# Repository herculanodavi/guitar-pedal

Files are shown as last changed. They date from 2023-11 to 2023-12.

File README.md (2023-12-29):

# guitar-pedal
Electronics project for the course Mixed-Signal Hardware Design with KiCad by Philip Salmony

## System Design
[System Requirements](system_design/requirements.md)

[Part Number Selection](system_design/part_selection.md)

## PCB
[Kicad Schematics](pcb/kicad)

[LTSpice Simulation Files](pcb/simulation)

[Gerber Files](pcb/gerber)

## Firmware
[Firmware Project](firmware)

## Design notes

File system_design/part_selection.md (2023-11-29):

# Part Selection

Given the reference design of the course, parts will only be different if there is a special reason to it, as part out of stock or additional functionality.

## Effect controls

- **Bistable buttons with LED:** LP4EE1PBCTR. It's a relatively cheap latched button with illumination. 2.2V illumination voltage and 0.1A current rating for 200mcd, so its consumption will be 1.5mA. 
- **Knobs for filter parameters:** PTV09A-4020F-B103. A cheap 10k linear single-gang potentiometer from Bourns.
- **Bistable footswitch:** (searching)
- **LED indicator:** T1341MND-20P000312U1930. The cheapest 1206 white LED I could find.
  
## USB

- **Receptacle:** 10164359-00011LF, the cheapest USB-C connector available in Digikey that is in stock.
- **ESD protection:** USBLC6-2SC6, from reference design.

## Processor

The suggested processor, STM32F103CBT6TR, is more expensive than STM32F401RBT6, while the F4 model has a Arm Core M4
and more RAM. The increased number of pins (from LQFP48 to LQFP64) is not an issue since this design is not constrained by space.

The main difference between our application and the one from the reference design is that we want to support a continuous and low-latency calculation of effects, and these are not yet specified. Thus, the trade-off of performance for space is advantageous. 

**Chosen part:** STM32F401RBT6

## Power supplies

Since requirements have no differences from the reference design, the parts will be the same. Reason to look for another pair of converters could if we had wanted to allow for the negotiable 500mA power consumption and consume more current (even so, this part would also be sufficient). At the time of the project, HT7533-1 was out of stock, so we chose a similar part: LDLN025M33R.

**Chosen parts:** TLV62569PDRLR (Buck) and LDLN025M33R (LDO).

## Converters

Since requirements have no differences from the reference design, the parts should be the same. Reason to look for another pair of converters could be to have a single-ended ADC or to invest in higher-performance parts, but these are not yet important enough to look for different parts. At the time of the project, both parts are active and in stock in Digikey.

**Chosen parts:** ADC141S616CIMM/NOPB (14-bit, 50-250kSPS, differential) and DAC7563SDGSR (12-bit, single-ended).

## Analogue sections

OPAmp part is the same as the reference design.

**Chosen part:** MCP6001

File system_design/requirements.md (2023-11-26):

# Guitar Pedal basic requirements

This is the project of a digital guitar pedal. It's a USB-powered, single-channel, low-frequency signal analyser and generator.

* USB-powered: less than 500mA current consumption, 5V input voltage, USB communication for configuring filter parameters.
* Low-frequency: Audio band (20Hz to 20kHz).
* Signal analyzer: captures the guitar signal input with an ADC for the digital generation of effects.
* Signal generator: transforms the generated guitar sound with effect back into analog.

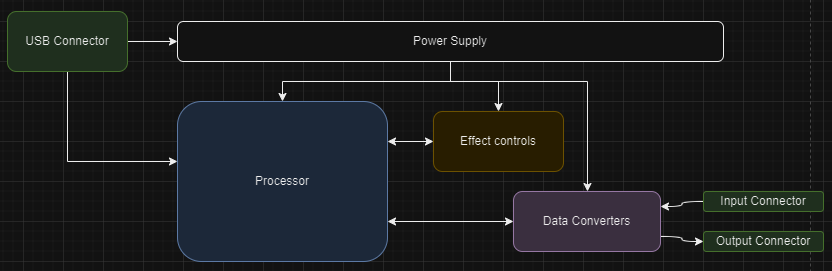
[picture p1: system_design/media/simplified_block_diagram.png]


# System requirements

Given basic requirments, let's dive deeper into each subsystem.

### Effect controls

- Two effects controls:
  - One latched pushbutton with LED for activation with 15mcd illuminance.
  - Three knobs for effect parameters.
- One footswitch for effect set.
- One LED with 15mcd illuminance for active mode indication.
- All controls should have ESD protection.

### USB

- **Bit rate:** audio band has max frequency of 20kHz, so sampling rate is at least 40kHz. Given a digital audio signal of 16 bits and a sampling rate of 2 times the minimum (80kHz), the minimum data rate is 1.28Mbits/s.
- **USB Version:** USB 2.0 FS is used: 12Mbits/s.
- **USB Connector:** USB Type C.
- **USB Power-only:** System should also work (pedal effects) with USB without data lines.

### Processor

- **Peripherals:**
  - USB for data streaming.
  - 2x SPI: ADC and DAC.
  - 6x ADC channel for effect knobs.
  - 3x GPIO input for activation buttons.
  - 1-3x GPIO output for LED (depending on the particular button with LED).
- **Core, packaging and brand:**
  - **Core:** Not much power needed, ARM Cortex M0 or M1 is enough.
  - **Package:** Avoid BGA and QFN
  - **Brand:** STM32

### Power supples
- Split digital and analogue supplies
  - Digital: switching supply for efficiency.
  - Analogue: LDO for noise performance.
- Input power from USB:
  - Noisy power rail.
  - Input voltage from 4.5V to 5V.
  - 500mA maximum current if negotiated, 150mA otherwise, so system should consume less than 150mA.

### Converters
- **Interface:** SPI
- **Bit depth:** 14-bit for ADC, 12-bit for DAC
- **Conversion:** Preferrably single-ended
- **Sampling rate:** At least 48kHz

### Analogue sections
- Input:
  - Greater than 1MOhm input buffer, ESD protection, RF filtering.
  - Anti-aliasing filter with cut-off at max half the ADC sampling rate.
- Output:
  - Smaller than 50Ohm outpuf buffer, ESD protection.
  - Anti-aliasing filter with cut-off at max half the DAC sampling rate.

### Miscellaneous
- **Additional connectors:** Tag-connect for firmware development.
- **Audio connectors:** TS 1/4”

## Requirements Draft

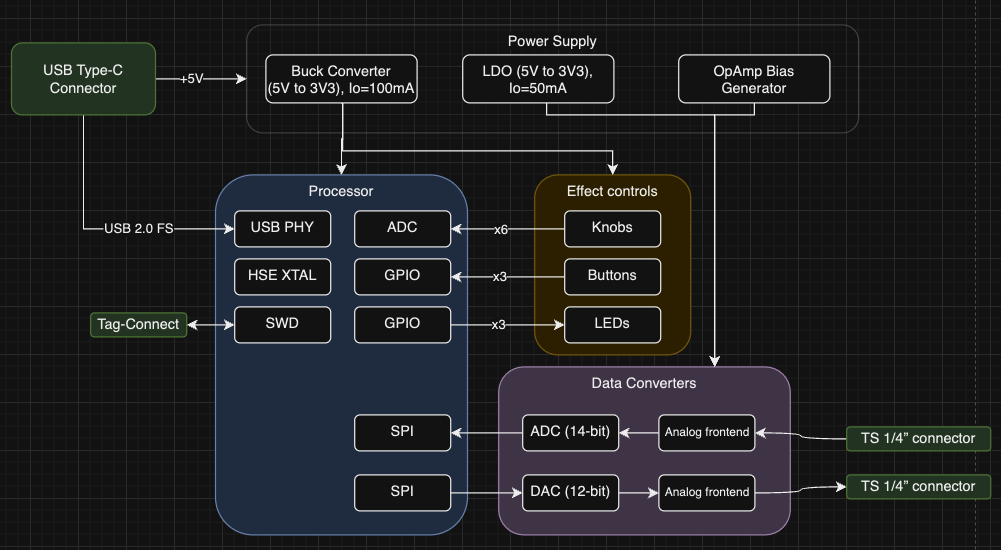
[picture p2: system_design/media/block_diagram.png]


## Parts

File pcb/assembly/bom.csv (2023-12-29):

Reference | Value | Footprint | Datasheet | Part Number | Part number | Supplier Link | Qtd
C201, C202, C306, C609 | 1u | Capacitor_SMD:C_0805_2012Metric | ~ | CC0805KKX7R7BB105 |  |  | 4
C203-C206, C208, C501 | 22u | Capacitor_SMD:C_0805_2012Metric | ~ | C0805C226M8PAC7210 |  |  | 6
C207 | DNP | Capacitor_SMD:C_0805_2012Metric | ~ |  |  |  | 1
C209, C302, C303, C305, C307, C309, C310, C312, C401-C409, C604, C607, C608, C611, C612, C614, C619, C622 | 100n | Capacitor_SMD:C_0805_2012Metric | ~ | CC0805JRX7R9BB104 |  |  | 25
C301, C311 | 4.7u | Capacitor_SMD:C_0805_2012Metric | ~ | C0805C475M4RACTU |  |  | 2
C304, C308 | 10p | Capacitor_SMD:C_0805_2012Metric | ~ | C0805C100M4GACTU |  |  | 2
C601-C603, C605, C610, C615 | 10u | Capacitor_SMD:C_0805_2012Metric | ~ | C0805C106M8RACTU |  |  | 6
C606, C618, C621, C623 | 150p | Capacitor_SMD:C_0805_2012Metric | ~ | 885012207111 |  |  | 4
C613, C616, C617, C620 | 1n | Capacitor_SMD:C_0805_2012Metric | ~ | C0805C102K2RAC |  |  | 4
D301-D305, D401-D405, D601, D602 | ~ | pedal-components:PESD3V3L1BA | PESD3V3L1BA | PESD3V3L1BA,115 |  |  | 12
H101-H105 | MountingHole | MountingHole:MountingHole_3.2mm_M3_DIN965_Pad | ~ |  |  |  | 5
J301 | TagConnect_TC2030 | Connector:Tag-Connect_TC2030-IDC-FP_2x03_P1.27mm_Vertical | https://www.tag-connect.com/wp-content/uploads/bsk-pdf-manager/TC2030-CTX_1.pdf |  |  |  | 1
J501 | USB4105-GF-A | Connector_USB:USB_C_Receptacle_GCT_USB4105-xx-A_16P_TopMnt_Horizontal | https://www.usb.org/sites/default/files/documents/usb_type-c.zip | USB4105-GF-A |  | https://www.digikey.de/en/products/detail/gct/USB4105-GF-A/11198441 | 1
J601, J602 | NMJ4HCD2 | pedal-components:NMJ4HCD2 |  | NMJ4HCD2 |  | https://www.mouser.de/ProductDetail/Neutrik/NMJ4HCD2?qs=SzdD80gJ2cAr9Xh3wJi7nw%3D%3D | 2
L201 | 10n | Inductor_SMD:L_0805_2012Metric | ~ | 0805CS-100EGTS |  |  | 1
L202 | 68u | pedal-components:ASPI-4030S-680M-T |  | ASPI-4030S-680M-T |  | https://www.digikey.de/en/products/detail/abracon-llc/ASPI-4030S-680M-T/5055591 | 1
R201 | 10R | Resistor_SMD:R_0805_2012Metric | ~ | RNCP0805FTD10R0 |  |  | 1
R202 | 100k | Resistor_SMD:R_0805_2012Metric | ~ | RT0805FRE07100KL |  |  | 1
R203 | 22k | Resistor_SMD:R_0805_2012Metric | ~ | RT0805FRE1322KL |  |  | 1
R204, R205 | 1k | Resistor_SMD:R_0805_2012Metric | ~ | RT0805FRE071KL |  |  | 2
R301, R609 | 0R | Resistor_SMD:R_0805_2012Metric | ~ | CRCW08050000Z0EC |  |  | 2
R302-R305, R601, R613 | 49.9R | Resistor_SMD:R_0805_2012Metric | ~ | CMP0805AFX-49R9ELF |  |  | 6
R306, R605 | 10K | Resistor_SMD:R_0805_2012Metric | ~ | AC0805FR-0710K5L |  |  | 2
R401-R407, R602, R614, R615 | 1K | Resistor_SMD:R_0805_2012Metric | ~ | RT0805FRE071KL |  |  | 10
R501, R502 | 5K1 | Resistor_SMD:R_0805_2012Metric | ~ | RT0805FRE135K1L |  |  | 2
R603, R604 | 2M2 | Resistor_SMD:R_0805_2012Metric | ~ | RCV08052M20FKEA |  |  | 2
R606, R608 | 6K8 | Resistor_SMD:R_0805_2012Metric | ~ | RT0805BRD076K8L |  |  | 2
R607, R611 | 22K | Resistor_SMD:R_0805_2012Metric | ~ | RT0805FRE1322KL |  |  | 2
R610, R612 | 12K | Resistor_SMD:R_0805_2012Metric | ~ | RP0805FRE0712KL |  |  | 2
RV401-RV406 | 50K Linear | pedal-components:PTV09A-4030S-A503 | ~ | PTV09A-4030S-A503 |  | https://www.digikey.de/en/products/detail/bourns-inc/PTV09A-4030S-A503/7314966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 | 6
SW401 | PBS-24-202P | pedal-components:FSW-DPDT-020 | ~ |  |  |  | 1
SW402, SW403 | LP4EE1PBCTR | pedal-components:LP4EE1PBCTR |  | LP4EE1PBCTR |  | https://www.digikey.de/en/products/detail/e-switch/LP4EE1PBCTR/4028429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 | 2
U201 | HT7533-1 | Package_TO_SOT_SMD:SOT-89-3 | https://www.holtek.com/documents/10179/116711/HT75xx-1v250.pdf |  |  |  | 1
U202 | TLV62569DBV | Package_TO_SOT_SMD:SOT-23-5 | http://www.ti.com/lit/ds/symlink/tlv62569.pdf | TLV62569DBVR |  | https://www.digikey.de/en/products/detail/texas-instruments/TLV62569DBVR/6580119 | 1
U203, U603, U605, U606 | MCP6001-OT | Package_TO_SOT_SMD:SOT-23-5 | http://ww1.microchip.com/downloads/en/DeviceDoc/21733j.pdf | MCP6001UT-I/OT |  | https://www.digikey.de/en/products/detail/microchip-technology/MCP6001UT-I-OT/562450 | 4
U301 | STM32F401RBTx | Package_QFP:LQFP-64_10x10mm_P0.5mm | https://www.st.com/resource/en/datasheet/stm32f401rb.pdf | STM32F401RBT6TR |  | https://www.digikey.de/en/products/detail/stmicroelectronics/STM32F401RBT6TR/5268280 | 1
U501 | USBLC6-2SC6 | Package_TO_SOT_SMD:SOT-23-6 | https://www.st.com/resource/en/datasheet/usblc6-2.pdf | USBLC6-2SC6 |  | https://www.digikey.de/en/products/detail/stmicroelectronics/USBLC6-2SC6/1040559 | 1
U601 | REF3033 | Package_TO_SOT_SMD:SOT-23 | http://www.ti.com/lit/ds/symlink/ref3033.pdf | REF3033AIDBZR |  | https://www.digikey.de/en/products/detail/texas-instruments/REF3033AIDBZR/1573916 | 1
U602 | DAC7563SDGSR | pedal-components:10-VSSOP-TI |  | DAC7563SDGSR |  | https://www.digikey.de/en/products/detail/texas-instruments/DAC7562SDGSR/2687106 | 1
U604 | ADC141S626 | pedal-components:10-VSSOP-TI |  | ADC141S626 |  | https://www.digikey.de/en/products/detail/texas-instruments/ADC141S626CIMM-NOPB/1835976 | 1
Y301 | 16MHz | pedal-components:RH100-16.000-8-2020-TR | ~ | RH100-16.000-8-2020-TR |  | https://www.digikey.com/en/products/detail/raltron-electronics/RH100-16-000-8-2020-TR/15963324 | 1

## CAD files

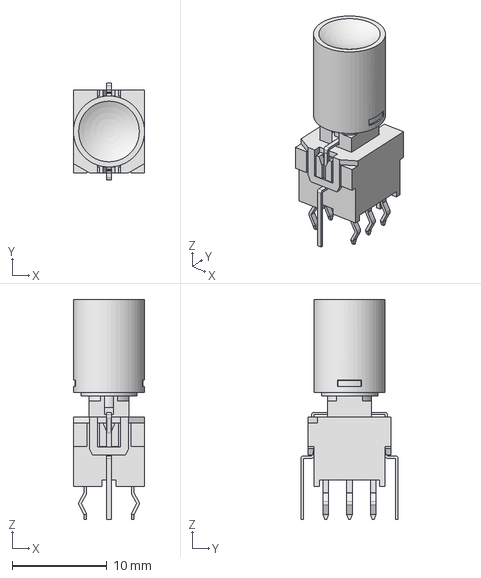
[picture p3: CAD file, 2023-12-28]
pcb/3d_model/components/LP4EE1PBCTR.stp
7.50 x 10.2 x 23.2 mm

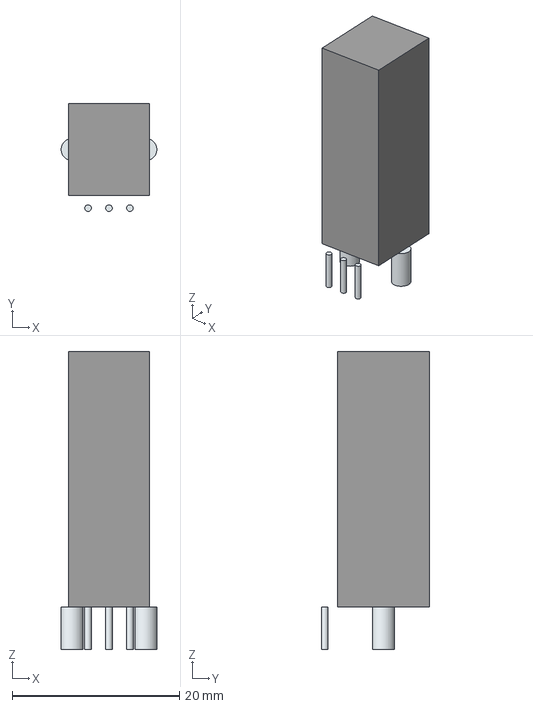
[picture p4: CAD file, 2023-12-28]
pcb/3d_model/components/PTV09A-4030S-A503.stp
11.4 x 12.9 x 35.6 mm
Leads

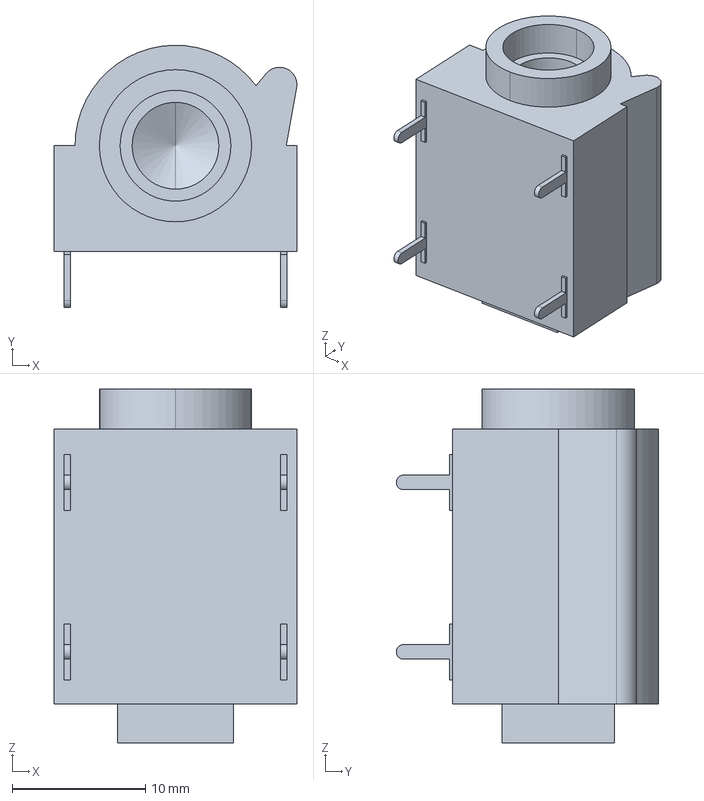
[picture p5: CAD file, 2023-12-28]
pcb/3d_model/components/d-nmj4hcd2.stp
18.2 x 19.7 x 26.5 mm

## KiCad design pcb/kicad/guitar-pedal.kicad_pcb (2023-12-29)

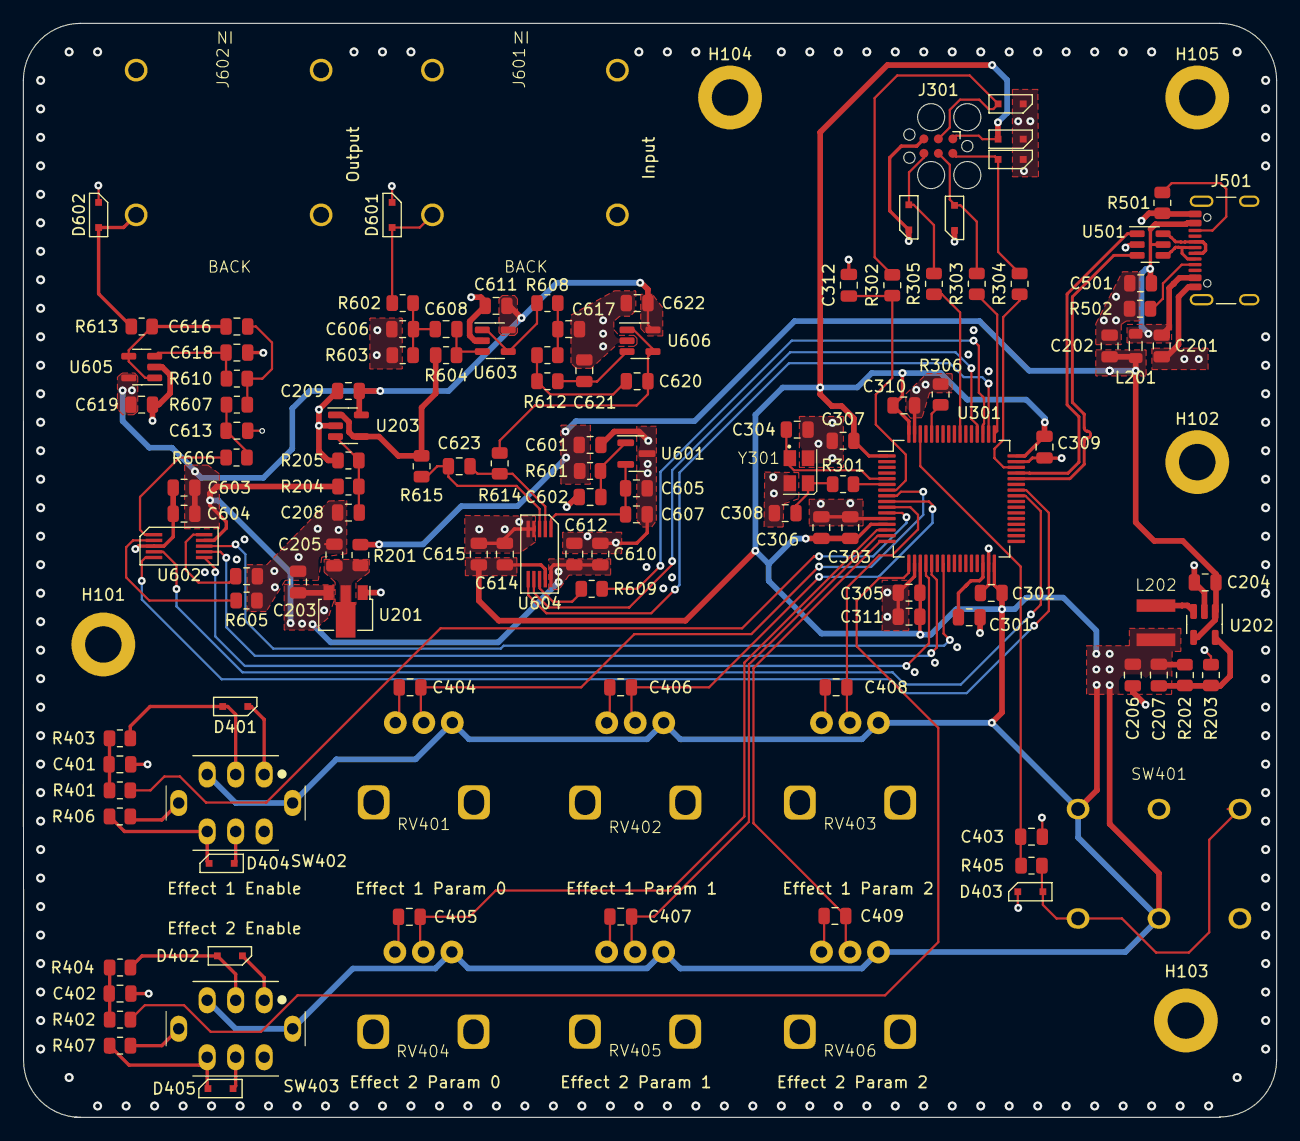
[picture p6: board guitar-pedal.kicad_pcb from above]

Board: 4 copper layers, 110.0 x 96.0 mm, 133 parts (0 on the bottom side), 76 nets.

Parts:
C201, C202, C306, C609: 1u; C_0805_2012Metric
C203, C204, C205, C206, C208, C501: 22u; C_0805_2012Metric
C207: DNP; C_0805_2012Metric
C209, C302, C303, C305, C307, C309, C310, C312, C401, C402, C403, C404, C405, C406, C407, C408, C409, C604, C607, C608, C611, C612, C614, C619, C622: 100n; C_0805_2012Metric
C301, C311: 4.7u; C_0805_2012Metric
C304, C308: 10p; C_0805_2012Metric
C601, C602, C603, C605, C610, C615: 10u; C_0805_2012Metric
C606, C618, C621, C623: 150p; C_0805_2012Metric
C613, C616, C617, C620: 1n; C_0805_2012Metric
D301, D302, D303, D304, D305, D401, D402, D403, D404, D405, D601, D602: PESD3V3L1BA
H101, H102, H103, H104, H105: MountingHole; MountingHole_3.2mm_M3_DIN965_Pad
J301: TagConnect_TC2030; Tag-Connect_TC2030-IDC-FP_2x03_P1.27mm_Vertical
J501: USB4105-GF-A; USB_C_Receptacle_GCT_USB4105-xx-A_16P_TopMnt_Horizontal
J601, J602: NMJ4HCD2
L201: 10n; L_0805_2012Metric
L202: 68u; ASPI-4030S-680M-T
R201: 10R; R_0805_2012Metric
R202: 100k; R_0805_2012Metric
R203: 22k; R_0805_2012Metric
R204, R205: 1k; R_0805_2012Metric
R301, R609: 0R; R_0805_2012Metric
R302, R303, R304, R305, R601, R613: 49.9R; R_0805_2012Metric
R306, R605: 10K; R_0805_2012Metric
R401, R402, R403, R404, R405, R406, R407, R602, R614, R615: 1K; R_0805_2012Metric
R501, R502: 5K1; R_0805_2012Metric
R603, R604: 2M2; R_0805_2012Metric
R606, R608: 6K8; R_0805_2012Metric
R607, R611: 22K; R_0805_2012Metric
R610, R612: 12K; R_0805_2012Metric
RV401, RV402, RV403, RV404, RV405, RV406: 50K Linear; PTV09A-4030S-A503
SW401: PBS-24-202P; FSW-DPDT-020
SW402, SW403: LP4EE1PBCTR
U201: HT7533-1; SOT-89-3
U202: TLV62569DBV; SOT-23-5
U203, U603, U605, U606: MCP6001-OT; SOT-23-5
U301: STM32F401RBTx; LQFP-64_10x10mm_P0.5mm
U501: USBLC6-2SC6; SOT-23-6
U601: REF3033; SOT-23
U602: DAC7563SDGSR; 10-VSSOP-TI
U604: ADC141S626; 10-VSSOP-TI
Y301: 16MHz; RH100-16.000-8-2020-TR

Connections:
+3.3VA: C205.1, C209.2, C603.1, C604.1, C610.1, C611.2, C612.1, C619.2, C622.2, R204.2, U201.3 (VOUT), U203.5 (V+), U602.9 (AVDD), U603.5 (V+), U604.10 (VA), U605.5 (V+), U606.5 (V+)
+3V3: C206.1, C207.1, C302.1, C303.1, C305.1, C306.1, C307.1, C309.1, C310.1, C311.1, C614.1, C615.1, D301.2 (A2), J301.1 (VCC), L202.2, R202.2, RV401.1, RV402.1, RV403.1, RV404.1, RV405.1, RV406.1, SW401.1 (A), SW401.4 (A), SW402.3, SW402.7 (L1), SW403.3, SW403.7 (L1), U301.1 (VBAT), U301.13 (VREF+), U301.19 (VDD), U301.32 (VDD), U301.48 (VDD), U301.64 (VDD), U604.9 (VIO)
+5V: C202.1, C204.1, C601.1, L201.2, R201.1, R601.1, U202.1 (EN), U202.4 (VIN)
/Data Converters/ADC_IN+: C623.2, R614.2, U604.2 (+IN)
/Data Converters/ADC_IN-: C623.1, R615.2, U604.3 (-IN)
/Data Converters/ADC_MISO: U301.52 (PC11), U604.7 (DOUT)
/Data Converters/ADC_NCS: U301.50 (PA15), U604.6 (nCS)
/Data Converters/ADC_SCLK: R609.2, U301.51 (PC10)
/Data Converters/ADC_VREF: C605.1, C607.1, U601.2 (OUT), U604.1 (VREF)
/Data Converters/ADC_VREF_VIN: C602.1, R601.2, U601.1 (IN)
/Data Converters/DAC_CS: U301.20 (PA4), U602.6 (NSYNC)
/Data Converters/DAC_MOSI: U301.23 (PA7), U602.8 (DIN)
/Data Converters/DAC_NCLR: U301.42 (PA9), U602.5 (NCLR)
/Data Converters/DAC_NLDAC: U301.41 (PA8), U602.4 (NLDAC)
/Data Converters/DAC_SCLK: U301.21 (PA5), U602.7 (SCLK)
/Effect Controls/EFFECT1_EN: R401.1, U301.11 (PC3)
/Effect Controls/EFFECT1_KNOB0: C404.1, RV401.2, U301.8 (PC0)
/Effect Controls/EFFECT1_KNOB1: C406.1, RV402.2, U301.9 (PC1)
/Effect Controls/EFFECT1_KNOB2: C408.1, RV403.2, U301.10 (PC2)
/Effect Controls/EFFECT2_EN: R402.1, U301.17 (PA3)
/Effect Controls/EFFECT2_KNOB0: C405.1, RV404.2, U301.14 (PA0)
/Effect Controls/EFFECT2_KNOB1: C407.1, RV405.2, U301.15 (PA1)
/Effect Controls/EFFECT2_KNOB2: C409.1, RV406.2, U301.16 (PA2)
/Effect Controls/PEDAL_EN: C403.1, R405.1, U301.62 (PB9)
/PowerSupply/5V_FILT: C203.1, R201.2, U201.2 (VIN)
/PowerSupply/BUCK_FB: C207.2, R202.1, R203.2, U202.5 (FB)
/PowerSupply/BUCK_SW: L202.1, U202.3 (SW)
/PowerSupply/VCOM_INPUT: C208.1, R204.1, R205.2, U203.3 (+)
/Processor/BOOT0: R306.2, U301.60 (BOOT0)
/Processor/D+: U301.45 (PA12), U501.1 (I/O1)
/Processor/D-: U301.44 (PA11), U501.3 (I/O2)
/Processor/HSE_IN: C304.1, U301.5 (PH0), Y301.1
/Processor/HSE_OUT: R301.2, U301.6 (PH1)
/Processor/HSE_PRE_OUT: C308.1, R301.1, Y301.3
/Processor/SWCLK: R303.2, U301.49 (PA14)
/Processor/SWDIO: R304.2, U301.46 (PA13)
/Processor/SWO: R305.2, U301.55 (PB3)
/Processor/TAG_SWCLK: D303.2 (A2), J301.4 (SWCLK), R303.1
/Processor/TAG_SWDIO: D304.2 (A2), J301.2 (SWDIO), R304.1
/Processor/TAG_SWO: D305.2 (A2), J301.6 (SWO), R305.1
/Processor/TAG_nRST: D302.2 (A2), J301.3 (~RESET), R302.1
/Processor/VCAP: C301.1, U301.30 (VCAP1)
/Processor/nRST: C312.1, R302.2, U301.7 (NRST)
/USB/CONN_D+: J501.A6 (D+), J501.B6 (D+), U501.6 (I/O1)
/USB/CONN_D-: J501.A7 (D-), J501.B7 (D-), U501.4 (I/O2)
GND: C201.2, C202.2, C203.2, C204.2, C205.2, C206.2, C208.2, C209.1, C301.2, C302.2, C303.2, C304.2, C305.2, C306.2, C307.2, C308.2, C309.2, C310.2, C311.2, C312.2, C401.2, C402.2, C403.2, C404.2, C405.2, C406.2, C407.2, C408.2, C409.2, C501.2, C601.2, C602.2, C603.2, C604.2, C605.2, C606.2, C607.2, C609.1, C610.2, C611.1, C612.2, C613.1, C614.2, C615.2, C617.1, C618.1, C619.1, C621.1, C622.1, D301.1 (A1), D302.1 (A1), D303.1 (A1), D304.1 (A1), D305.1 (A1), D401.1 (A1), D402.1 (A1), D403.1 (A1), D404.2 (A2), D405.2 (A2), D601.1 (A1), D602.1 (A1), J301.5 (GND), J501.A1 (GND), J501.A12 (GND), J501.B1 (GND), J501.B12 (GND), J601.2, J601.3, J601.4, J602.2, J602.3, J602.4, R203.1, R205.1, R306.1, R501.1, R502.1, R603.2, R605.1, RV401.3, RV402.3, RV403.3, RV404.3, RV405.3, RV406.3, SW401.3 (C), SW401.6 (C), SW402.1, SW402.5, SW403.1, SW403.5, U201.1 (GND), U202.2 (GND), U203.2 (V-), U301.12 (VSSA), U301.18 (VSS), U301.31 (VSS), U301.47 (VSS), U301.63 (VSS), U501.2 (GND), U601.3 (GND), U602.3 (GND), U603.2 (V-), U604.4 (GND), U604.5 (GND), U605.2 (V-), U606.2 (V-), Y301.2, Y301.4
unnamed: C401.1, R401.2, R403.1
unnamed: C402.1, R402.2, R404.1
unnamed: C606.1, C608.1, R602.2, R603.1
unnamed: C613.2, R606.2, R607.1
unnamed: C616.2, R607.2, R610.1
unnamed: C617.2, R608.2, R611.1
unnamed: C620.2, R611.2, R612.1
unnamed: D401.2 (A2), R403.2, SW402.2
unnamed: D402.2 (A2), R404.2, SW403.2
unnamed: D403.2 (A2), R405.2, SW401.2 (B), SW401.5 (B)
unnamed: D404.1 (A1), R406.2, SW402.6
unnamed: D405.1 (A1), R407.2, SW403.6
unnamed: D601.2 (A2), J601.1, R602.1
unnamed: D602.2 (A2), J602.1, R613.2
unnamed: J501.A5 (CC1), R502.2
unnamed: J501.B5 (CC2), R501.2
unnamed: R406.1, SW402.8 (L2)
unnamed: R407.1, SW403.8 (L2)
unnamed: R606.1, U602.1 (VOUT_A)
unnamed: R605.2, U602.2 (VOUT_B)
unnamed: C609.2, U602.10 (VREFIN/OUT)
unnamed: C608.2, R604.2, U603.3 (+)
unnamed: R608.1, U603.1, U603.4 (-)
unnamed: R609.1, U604.8 (SCLK)
unnamed: C618.2, R610.2, U605.3 (+)
unnamed: C616.1, R613.1, U605.1, U605.4 (-)
unnamed: C621.2, R612.2, U606.3 (+)
unnamed: C620.1, R614.1, U606.1, U606.4 (-)
VBUS: C201.1, C501.1, J501.A4 (VBUS), J501.A9 (VBUS), J501.B4 (VBUS), J501.B9 (VBUS), L201.1, U501.5 (VBUS)
VCOM: R604.1, R615.1, U203.1, U203.4 (-)

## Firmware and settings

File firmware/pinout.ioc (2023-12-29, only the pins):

Mcu.UserName=STM32F401RBTx
PA0-WKUP.GPIO_Label=EFFECT2_KNOB0
PA0-WKUP.Signal=ADCx_IN0
PA1.GPIO_Label=EFFECT2_KNOB1
PA1.Signal=ADCx_IN1
PA11.GPIO_Label=USB_N
PA11.Signal=USB_OTG_FS_DM
PA12.GPIO_Label=USB_P
PA12.Signal=USB_OTG_FS_DP
PA13.GPIO_Label=PROG_SWDIO
PA13.Signal=SYS_JTMS-SWDIO
PA14.GPIO_Label=PROG_SWCLK
PA14.Signal=SYS_JTCK-SWCLK
PA15.GPIO_Label=ADC_NCS
PA15.Signal=SPI3_NSS
PA2.GPIO_Label=EFFECT2_KNOB2
PA2.Signal=ADCx_IN2
PA3.GPIO_Label=EFFECT2_EN
PA3.Signal=GPIO_Input
PA4.GPIO_Label=DAC_NCS
PA4.Signal=SPI1_NSS
PA5.GPIO_Label=DAC_SCLK
PA5.Signal=SPI1_SCK
PA7.GPIO_Label=DAC_MOSI
PA7.Signal=SPI1_MOSI
PA8.GPIO_Label=DAC_NLDAC
PA8.Signal=GPIO_Output
PA9.GPIO_Label=DAC_NCLR
PA9.Signal=GPIO_Output
PB0.GPIO_Label=DAC_INT
PB0.Signal=GPXTI0
PB3.GPIO_Label=PROG_SWO
PB3.Signal=SYS_JTDO-SWO
PB9.GPIO_Label=PEDAL_EN
PB9.Signal=GPIO_Input
PC0.GPIO_Label=EFFECT1_KNOB0
PC0.Signal=ADCx_IN10
PC1.GPIO_Label=EFFECT1_KNOB1
PC1.Signal=ADCx_IN11
PC10.GPIO_Label=ADC_SCLK
PC10.Signal=SPI3_SCK
PC11.GPIO_Label=ADC_MISO
PC11.Signal=SPI3_MISO
PC2.GPIO_Label=EFFECT1_KNOB2
PC2.Signal=ADCx_IN12
PC3.GPIO_Label=EFFECT1_EN
PC3.Signal=GPIO_Input

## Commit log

2023-11-26 Add luminance to LED requirement
2023-11-26 Add part selection for MCU, regulator and converters
2023-11-29 Add knob and LED in parts selection.
2023-12-10 Add top-level schematic sheet.
    [controls.kicad_sch, converters.kicad_sch, guitar-pedal.kicad_pcb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]
2023-12-10 Add power supply circuit and MCU symbol.
    [guitar-pedal.kicad_sch, power_supply.kicad_sch, processor.kicad_sch]
2023-12-10 Move project files to kicad directory.
    [controls.kicad_sch, converters.kicad_sch, guitar-pedal.kicad_pcb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]
2023-12-10 Add bias generator.
    [power_supply.kicad_sch]
2023-12-10 Move USB to own sheet.
    [guitar-pedal.kicad_sch, processor.kicad_sch, usb.kicad_sch]
2023-12-10 Add SoC and pinout.
    [guitar-pedal.kicad_sch, processor.kicad_sch, usb.kicad_sch]
2023-12-17 Add hse circuit.
    [processor.kicad_sch]
2023-12-17 Added ADC digital part.
    [converters.kicad_sch, guitar-pedal.kicad_sch]
2023-12-26 Added converters, controls and updated annotations.
    [controls.kicad_sch, converters.kicad_sch, guitar-pedal.kicad_sch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]
2023-12-26 Started PCB placement.
    [guitar-pedal.kicad_pcb]
2023-12-28 Added PCB layout and fabrication output.
    [LP4EE1PBCTR.stp, PTV09A-4030S-A503.stp, bom.csv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]
2023-12-29 Add ltspice simulations.
    [converters.kicad_sch]
2023-12-29 Update .ioc file and fix DAC pinout.
    [guitar-pedal-B_Cu.gbr, guitar-pedal-B_Mask.gbr, guitar-pedal-B_Paste.gbr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]
2023-12-29 Add part numbers to components for ordering.
    [bom.csv, controls.kicad_sch, converters.kicad_sch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]
